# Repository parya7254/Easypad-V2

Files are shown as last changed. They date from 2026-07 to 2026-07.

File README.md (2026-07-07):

# Easypad-V2
A compact macropad featuring RGB lighting with SK6812 MINI-E Neopixel LEDs, a rotary encoder, a SSD1306 OLED Display and 15 (low-profile) choc mechanical switches! Powered by KMK firmware!



# Features:
Per-key RGB lighting via SK6812 MINI-E RGB LEDs, page scrolling via the onboard EC11 rotary encoder, a 0.91" 128x32 SSD1306 OLED display to display current mode, and 15 tactile low profile Kalih Choc V1 switches for compactability.

# Why?
I wanted to experiment with compact designs and Choc switches. I built this to help get the grasp of making keyboards/macropads with Kalih Choc switches since they have a different pin layout and are way more compact. I also wanted to make this because I really love designing hardware projects and PCBs in general every chance I get time.

# Schematic:


# PCB: 




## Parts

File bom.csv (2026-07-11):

Column 1 | Column 2 | Column 3 | Column 4
Part | Source | Quantity | Cost
PCB | JLCPCB | 5 (MOQ) | $5.30 (with Shipping)
Header Pins | AliExpress | 1 (comes with 5 male-female sets) | $1.79
RPi Pico (clone) | AliExpress | 1 | $2.79
128x32 OLED | AliExpress | 1 | $1.99
Switches | AliExpress | 2 sets of 10pcs | $5.79
1N4148W Diodes | AliExpress | 100 | $1.48
SK6812 Mini E LEDs | AliExpress | 100pcs | $7.33
Rotary Encoder | AliExpress | 5 | $3.58
Clear Keycaps | AliExpress | 20 | $5.45

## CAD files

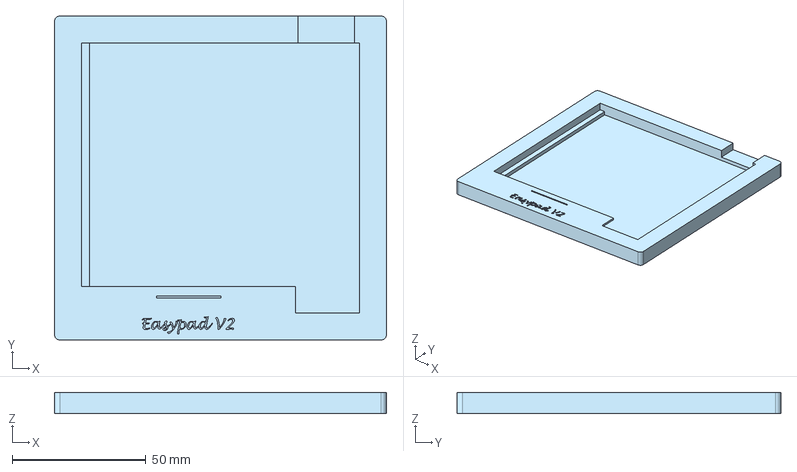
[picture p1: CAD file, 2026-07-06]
CAD/Easypad V2 - Case.step
124.0 x 121.0 x 8.00 mm

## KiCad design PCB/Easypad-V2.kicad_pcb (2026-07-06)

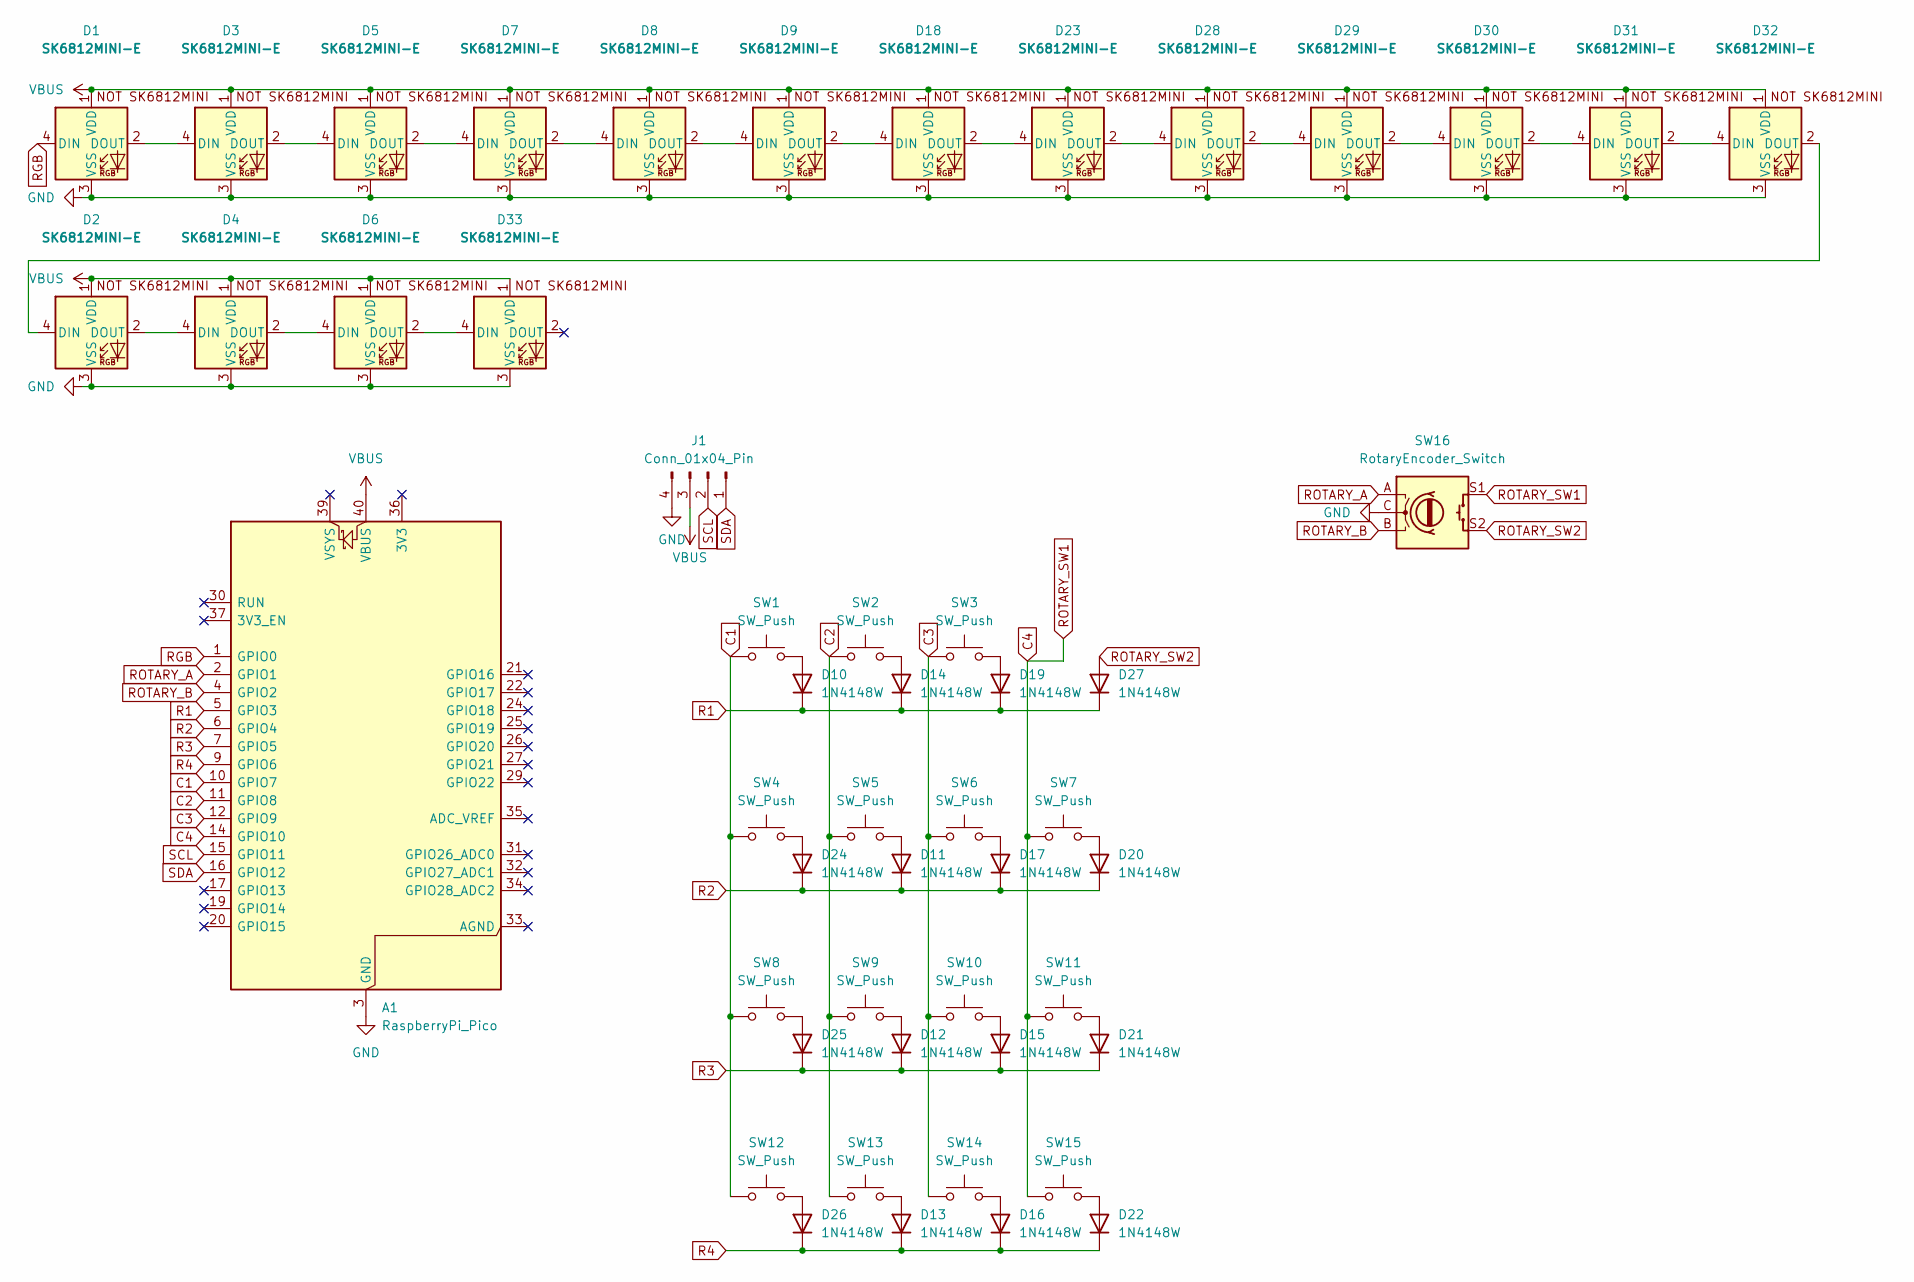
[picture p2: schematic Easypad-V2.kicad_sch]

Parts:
A1: RaspberryPi_Pico; RaspberryPi_Pico_Common_Unspecified
D1, D2, D3, D4, D5, D6, D7, D8, D9, D18, D23, D28, D29, D30, D31, D32, D33: SK6812MINI-E; MX_SK6812MINI-E_REV
D10, D11, D12, D13, D14, D15, D16, D17, D19, D20, D21, D22, D24, D25, D26, D27: 1N4148W; D_SOD-123
J1: Conn_01x04_Pin; PinHeader_1x04_P2.54mm_Vertical
SW1, SW2, SW3, SW4, SW5, SW6, SW7, SW8, SW9, SW10, SW11, SW12, SW13, SW14, SW15: SW_Push; Choc_V1_1.00u
SW16: RotaryEncoder_Switch; RotaryEncoder_Alps_EC11E-Switch_Vertical_H20mm

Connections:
C1: A1.10 (GPIO7), SW1.1, SW4.1, SW8.1, SW12.1
C2: A1.11 (GPIO8), SW2.1, SW5.1, SW9.1, SW13.1
C3: A1.12 (GPIO9), SW3.1, SW6.1, SW10.1, SW14.1
C4: A1.14 (GPIO10), SW7.1, SW11.1, SW15.1, SW16.S1
GND: A1.3 (GND), A1.8 (GND), A1.13 (GND), A1.18 (GND), A1.23 (GND), A1.28 (GND), A1.38 (GND), D1.3 (VSS), D2.3 (VSS), D3.3 (VSS), D4.3 (VSS), D5.3 (VSS), D6.3 (VSS), D7.3 (VSS), D8.3 (VSS), D9.3 (VSS), D18.3 (VSS), D23.3 (VSS), D28.3 (VSS), D29.3 (VSS), D30.3 (VSS), D31.3 (VSS), D32.3 (VSS), D33.3 (VSS), J1.4, SW16.C
unnamed: D1.2 (DOUT), D3.4 (DIN)
unnamed: D2.4 (DIN), D32.2 (DOUT)
unnamed: D2.2 (DOUT), D4.4 (DIN)
unnamed: D3.2 (DOUT), D5.4 (DIN)
unnamed: D4.2 (DOUT), D6.4 (DIN)
unnamed: D5.2 (DOUT), D7.4 (DIN)
unnamed: D7.2 (DOUT), D8.4 (DIN)
unnamed: D8.2 (DOUT), D9.4 (DIN)
unnamed: D10.2 (A), SW1.2
unnamed: D11.2 (A), SW5.2
unnamed: D12.2 (A), SW9.2
unnamed: D13.2 (A), SW13.2
unnamed: D14.2 (A), SW2.2
unnamed: D15.2 (A), SW10.2
unnamed: D16.2 (A), SW14.2
unnamed: D17.2 (A), SW6.2
unnamed: D9.2 (DOUT), D18.4 (DIN)
unnamed: D18.2 (DOUT), D23.4 (DIN)
unnamed: D19.2 (A), SW3.2
unnamed: D20.2 (A), SW7.2
unnamed: D21.2 (A), SW11.2
unnamed: D22.2 (A), SW15.2
unnamed: D23.2 (DOUT), D28.4 (DIN)
unnamed: D24.2 (A), SW4.2
unnamed: D25.2 (A), SW8.2
unnamed: D26.2 (A), SW12.2
unnamed: D28.2 (DOUT), D29.4 (DIN)
unnamed: D29.2 (DOUT), D30.4 (DIN)
unnamed: D30.2 (DOUT), D31.4 (DIN)
unnamed: D31.2 (DOUT), D32.4 (DIN)
unnamed: D6.2 (DOUT), D33.4 (DIN)
R1: A1.5 (GPIO3), D10.1 (K), D14.1 (K), D19.1 (K), D27.1 (K)
R2: A1.6 (GPIO4), D11.1 (K), D17.1 (K), D20.1 (K), D24.1 (K)
R3: A1.7 (GPIO5), D12.1 (K), D15.1 (K), D21.1 (K), D25.1 (K)
R4: A1.9 (GPIO6), D13.1 (K), D16.1 (K), D22.1 (K), D26.1 (K)
RGB: A1.1 (GPIO0), D1.4 (DIN)
ROTARY_A: A1.2 (GPIO1), SW16.A
ROTARY_B: A1.4 (GPIO2), SW16.B
ROTARY_SW2: D27.2 (A), SW16.S2
SCL: A1.15 (GPIO11), J1.2
SDA: A1.16 (GPIO12), J1.1
VBUS: A1.40 (VBUS), D1.1 (VDD), D2.1 (VDD), D3.1 (VDD), D4.1 (VDD), D5.1 (VDD), D6.1 (VDD), D7.1 (VDD), D8.1 (VDD), D9.1 (VDD), D18.1 (VDD), D23.1 (VDD), D28.1 (VDD), D29.1 (VDD), D30.1 (VDD), D31.1 (VDD), D32.1 (VDD), D33.1 (VDD), J1.3

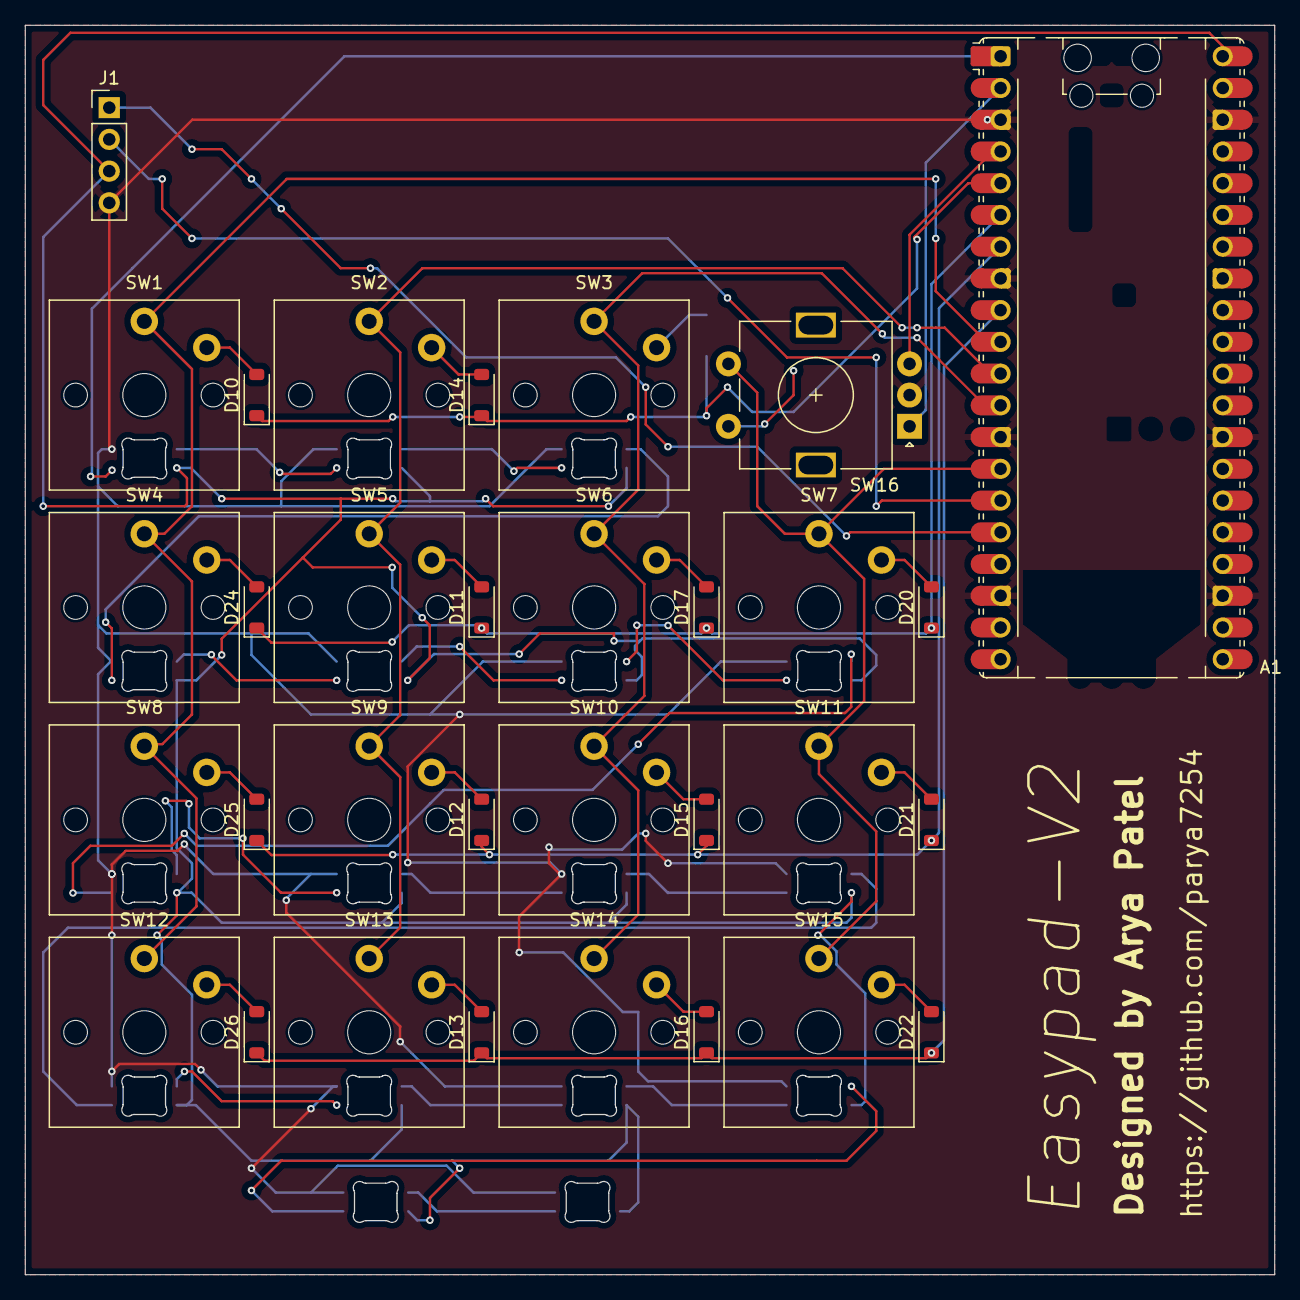
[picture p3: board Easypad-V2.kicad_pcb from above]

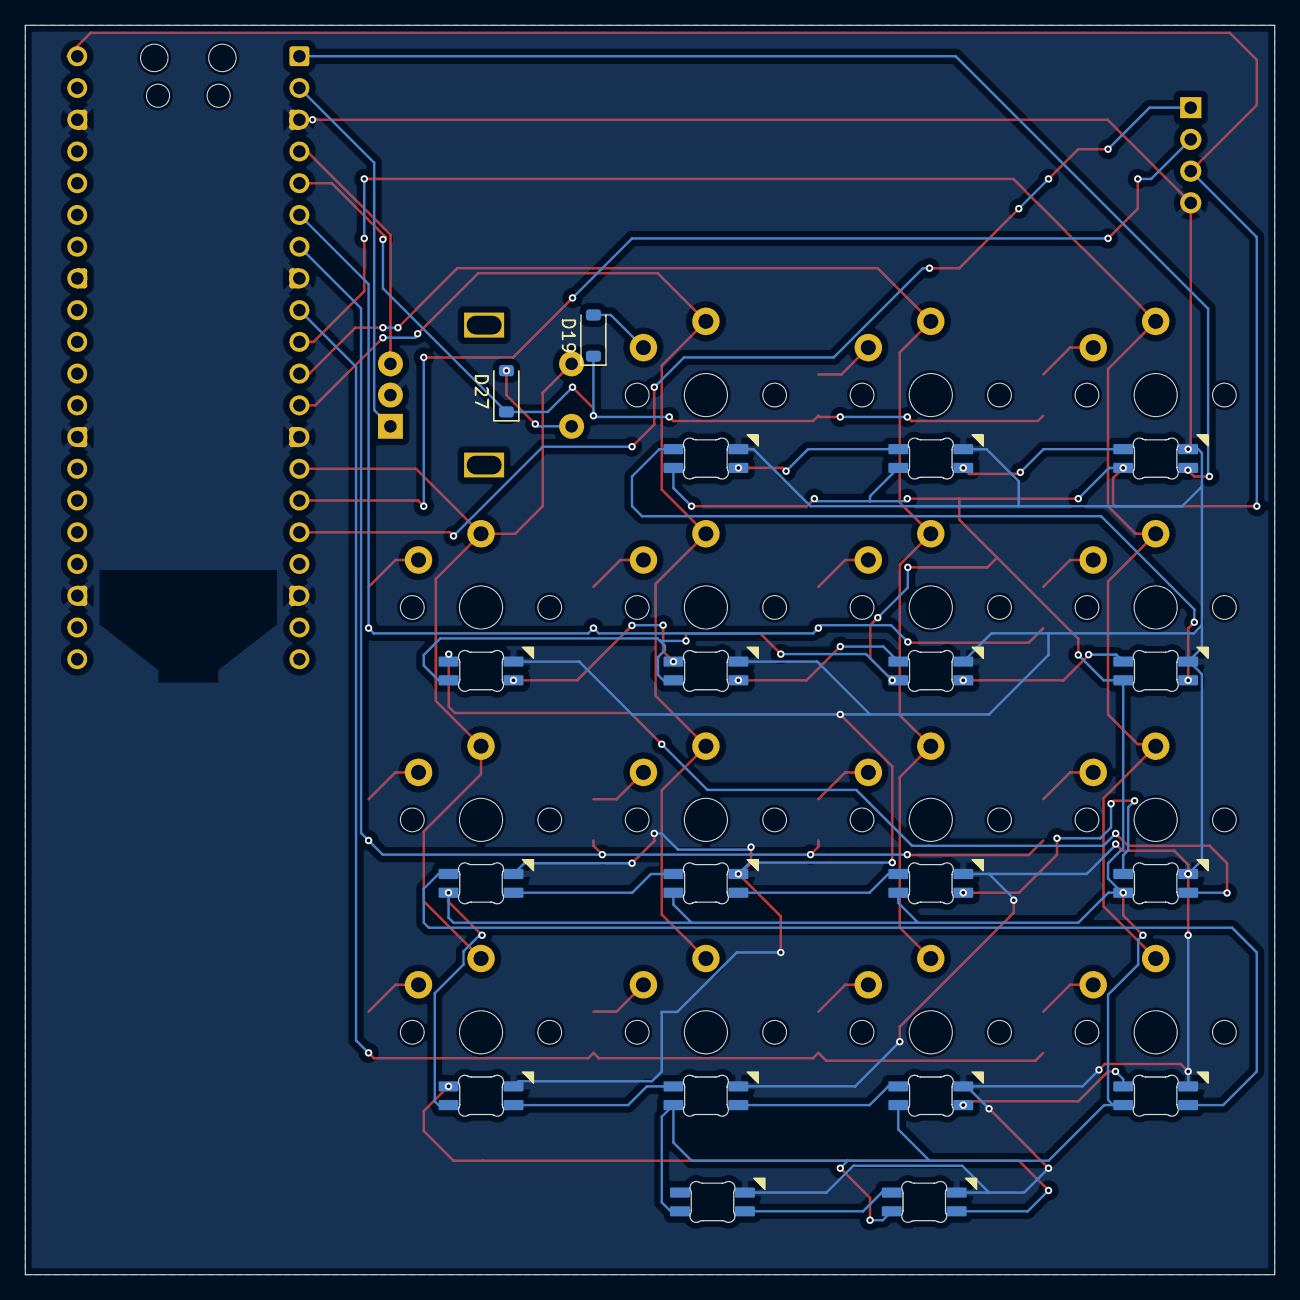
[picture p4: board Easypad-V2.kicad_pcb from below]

Board: 2 copper layers, 100.0 x 100.0 mm, 51 parts (2 on the bottom side), 47 nets.

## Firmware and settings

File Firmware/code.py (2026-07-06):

import board
import busio
from kmk.kmk_keyboard import KMKKeyboard
from kmk.keys import KC
from kmk.scanners import DiodeOrientation
from kmk.modules.macros import Press, Release, Tap, Macros
from kmk.extensions.rgb import RGB
from kmk.modules.layers import Layers
from kmk.extensions.display import Display, SSD1306, TextEntry
from kmk.modules.encoder import EncoderHandler
from kmk.modules.mouse_keys import MouseKeys

keyboard = KMKKeyboard()

mousekeys = MouseKeys(
    max_speed = 10,
    acc_interval = 100, # Delta ms to apply acceleration
    move_step = 0.6
)

keyboard.modules.append(MouseKeys())

encoder_handler = EncoderHandler()

encoder_handler.pins = ((board.GP1, board.GP2, None, False),)

keyboard.col_pins = (board.GP7, board.GP8, board.GP9, board.GP10)
keyboard.row_pins = (board.GP3, board.GP4, board.GP5, board.GP6)
keyboard.diode_orientation = DiodeOrientation.COL2ROW
keyboard.modules.append(Layers())

rgb = RGB(pixel_pin=board.GP0, num_pixels=18)
keybaord.extensions.append(rgb)

i2c_bus = busio.I2C(board.GP11, board.GP12)
display_driver = SSD1306(
    i2c=i2c_bus,
)

display = Display(
    display=display_driver,
    entries=[
        TextEntry(text='Mode: ', x=0, y=32, y_anchor='B'),
        TextEntry(text='Numpad', x=40, y=32, y_anchor='B', layer=0),
        TextEntry(text='RGB', x=40, y=32, y_anchor='B', layer=1),
        TextEntry(text='FUNC', x=40, y=32, y_anchor='B', layer=2),
        TextEntry(text='0 1 2', x=0, y=4),
        TextEntry(text='0', x=0, y=4, inverted=True, layer=0),
        TextEntry(text='1', x=12, y=4, inverted=True, layer=1),
        TextEntry(text='2', x=24, y=4, inverted=True, layer=2),
    ],
    
    width=128,
    height=32,
    dim_time=4,
    dim_target=0,
    off_time=10,
    brightness=1,
)

keyboard.extensions.append(display)

keyboard.modules.append(Macros())

L0= KC.DF(0)
L1= KC.DF(1)
L2= KC.DF(2)

keyboard.keymap = [
    # Keymap for Layer 0 (Numpad Mode)
    [
        KC.KP_7, KC.KP_8, KC.KP_9, L1,
        KC.KP_4, KC.KP_5, KC.KP_6, KC.KP_PLUS,
        KC.KP_7. KC.KP_8, KC.KP_9, KC.KP_ENTER,
        KC.KP_0, KC.KP_0, KC.KP_DOT, KC.KP_ENTER,
    ],
    # Keymap for Layer 1 (RGB Control)
    [
        KC.RGB_TOG, KC.RGB_HUI, KC.RGB_HUD, L2
        KC.RGB_SAI, KC.RGB_SAD, KC.RGB_VAI,  KC.RGB_VAD,
        KC.RGB_MODE_SWIRL, KC.RGB_MODE_KNIGHT, KC.RGB_MODE_BREATHE_RAINBOW, KC.RGB_MODE_RAINBOW,
        KC.RGB_MODE_BREATHE, KC.RGB_MODE_PLAIN, KC.RGB_ANI, KC.RGB_AND,
    ],
    # Keymap for Layer 2 (Function Keys)
    [
        KC.F1, KC.F2, KC.F3, L0
        KC.F4, KC.F5, KC.F6, KC.F7,
        KC.F8, KC.F9, KC.F10, KC.F11,
        KC.F12, KC.NO, KC.NO, KC.NO,
    ],
]

encoder_handler.map = [ ((KC.MW_UP, KC.MW_DOWN),),
                        ((KC.MW_UP, KC.MW_DOWN),),
                        ((KC.MW_UP, KC.MW_DOWN),),
                        ]

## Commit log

2026-07-06 Uploaded All Files!!
    [Easypad V2 - Case.step, Easypad-V2.kicad_pcb, Easypad-V2.kicad_sch]
2026-07-11 Format bom.csv with proper CSV structure
    [bom.csv]
2026-07-11 Reformat bom.csv to remove leading dashes
    [bom.csv]
2026-07-11 Add BOM section to README
    Added a Bill of Materials (BOM) section with details on parts, sources, quantities, and costs.
2026-07-22 Create CAD Link
2026-07-22 Add CAD link and enhance BOM with source links
    Added CAD link and updated BOM table with links to sources.
2026-07-22 Add links to components in BOM
    Updated BOM to include links for each part.
    [bom.csv]
2026-07-22 Add firmware flashing instructions to README
    Added instructions for flashing firmware to the macropad using CircuitPython and KMK.
2026-08-07 Update PCB images and add old PCB section
    Added new PCB image and an old PCB section to README.
2026-08-07 Add 3D Printer Filament entry to bom.csv
2026-08-07 Add 3D Printer Filament entry to README
2026-11-08 Remove 3D Printer Filament entry from README
2026-11-08 Add total cost row to bom.csv
2026-11-08 Revise PCB images and format old PCBs section
    Updated images and added a table for old PCBs in the README.
2026-11-08 Update section title for old PCB revisions
2026-11-08 Update section title from 'Old' to 'Previous' PCB Revisions
2026-11-08 Add screws to BOM and update total cost
